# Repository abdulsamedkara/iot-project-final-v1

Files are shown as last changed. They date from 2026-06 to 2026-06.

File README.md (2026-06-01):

<div align="center">
  <h1>🧠 ESP32 SmartLab Asistanı (SmartLab Assistant)</h1>
  <p><strong>Yapay Zeka Destekli, Uçtan Uca Şifreli, Çoklu Sensörlü Akıllı Laboratuvar Sistemi</strong></p>
  <p>
    <a href="#english">🇬🇧 English</a> | <a href="#turkce">🇹🇷 Türkçe</a>
  </p>
</div>

---

## 🇬🇧 English

### 📖 About The Project

This project is an advanced **SmartLab Assistant** running on the **ESP32** microcontroller. It serves as a secure, voice-controlled IoT hub that monitors laboratory environments and interacts with users via **Local Large Language Models (LLM)** and **RAG (Retrieval-Augmented Generation)**. It features real-time sensor data streaming, AES-256 encrypted WebSocket communication, and a comprehensive Web UI for remote monitoring and control.

### ✨ Key Features

- **🗣️ Voice Interaction (STT & TTS):** Captures audio via I2S microphone (INMP441), streams it securely, and plays back LLM responses via I2S amplifier (MAX98357A).
- **🧠 AI & RAG Integration:** Processes voice commands using a local LLM (Ollama) and answers questions based on local PDF documents using RAG (Langchain).
- **🛡️ Secure Access & Encryption:** Uses MFRC522 RFID for user authentication. All audio data over WebSockets is encrypted using AES-256-CBC.
- **🌡️ Multi-Sensor Environment Monitoring:** Tracks Temperature & Humidity (DHT11), Air Quality/Smoke (MQ135), Light (LDR), Motion (PIR), Flame, and Vibration (SW-420).
- **⚙️ Automated Actuators:** Controls an exhaust Fan (PWM) and LED Strips automatically based on environmental thresholds or manual Web UI overrides.
- **🌐 Real-Time Web Dashboard:** A sleek Web UI to monitor live sensor telemetry, control actuators, and view chat history.

### 🛠️ Architecture & Technologies

- **Hardware:** ESP32, INMP441, MAX98357A, ILI9341 LCD, MFRC522 RFID, MQ135, DHT11, LDR, PIR, Flame, SW-420, L298N Motor Driver.
- **Embedded:** C, ESP-IDF (v5.x), FreeRTOS.
- **Server & Backend:** Python 3.10+, FastAPI, WebSockets, Piper TTS, Ollama (Local LLM), Langchain (RAG), ChromaDB.
- **Frontend:** HTML, CSS, JavaScript (Vanilla).

### 🖼️ Circuit Diagram

Below is the circuit diagram showing the hardware components and connections of the project. This diagram was prepared using **Fritzing**.

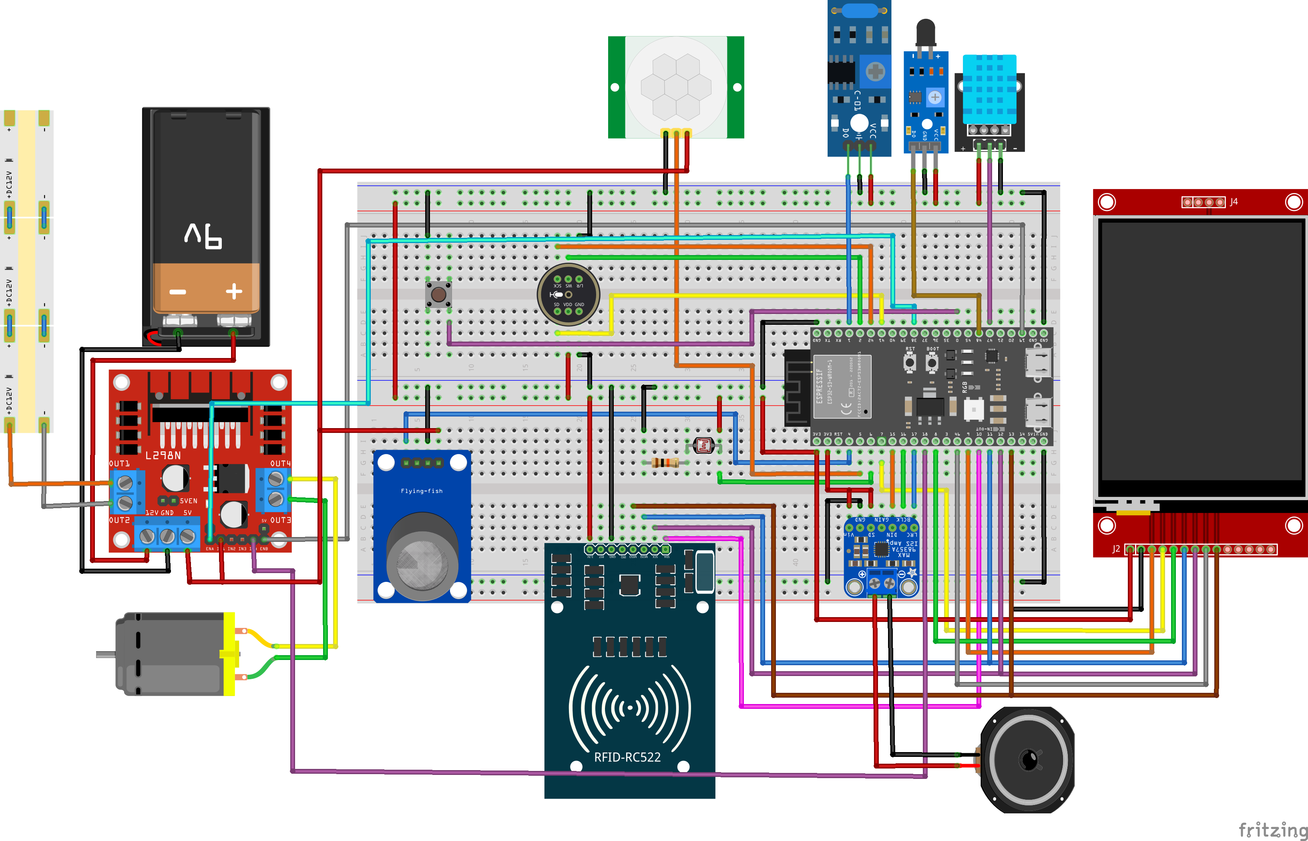
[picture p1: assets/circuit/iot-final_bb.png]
Circuit Diagram


### 🖥️ Web Dashboard Screenshots

Below are the screenshots of the Web UI used for live telemetry and environment control.

<p align="center">
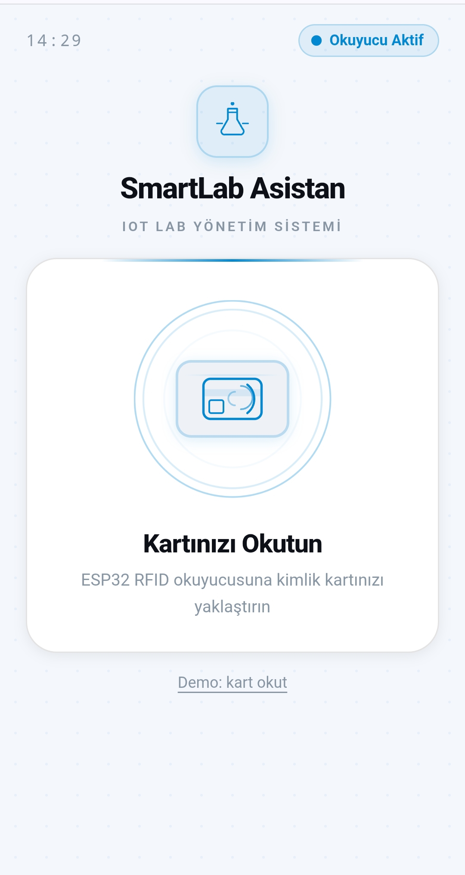
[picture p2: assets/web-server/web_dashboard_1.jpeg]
  
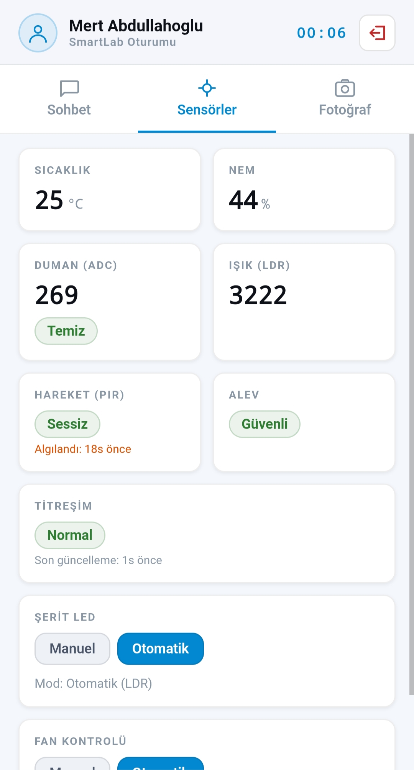
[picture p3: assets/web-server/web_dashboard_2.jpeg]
  
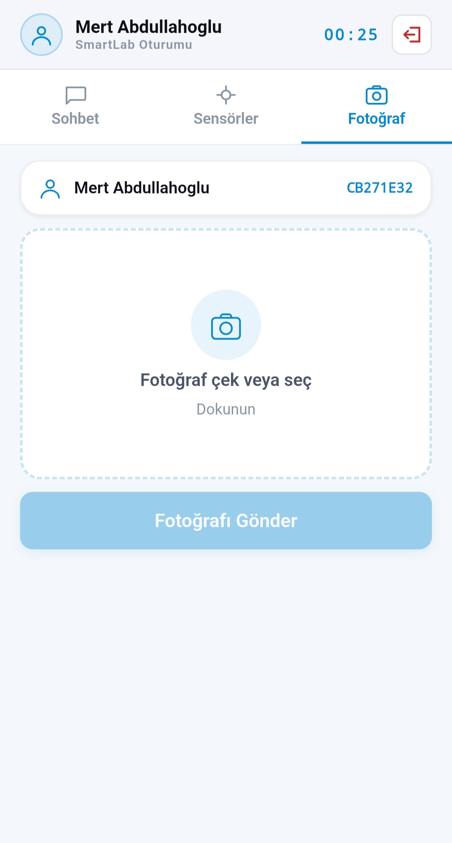
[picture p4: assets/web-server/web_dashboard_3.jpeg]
  
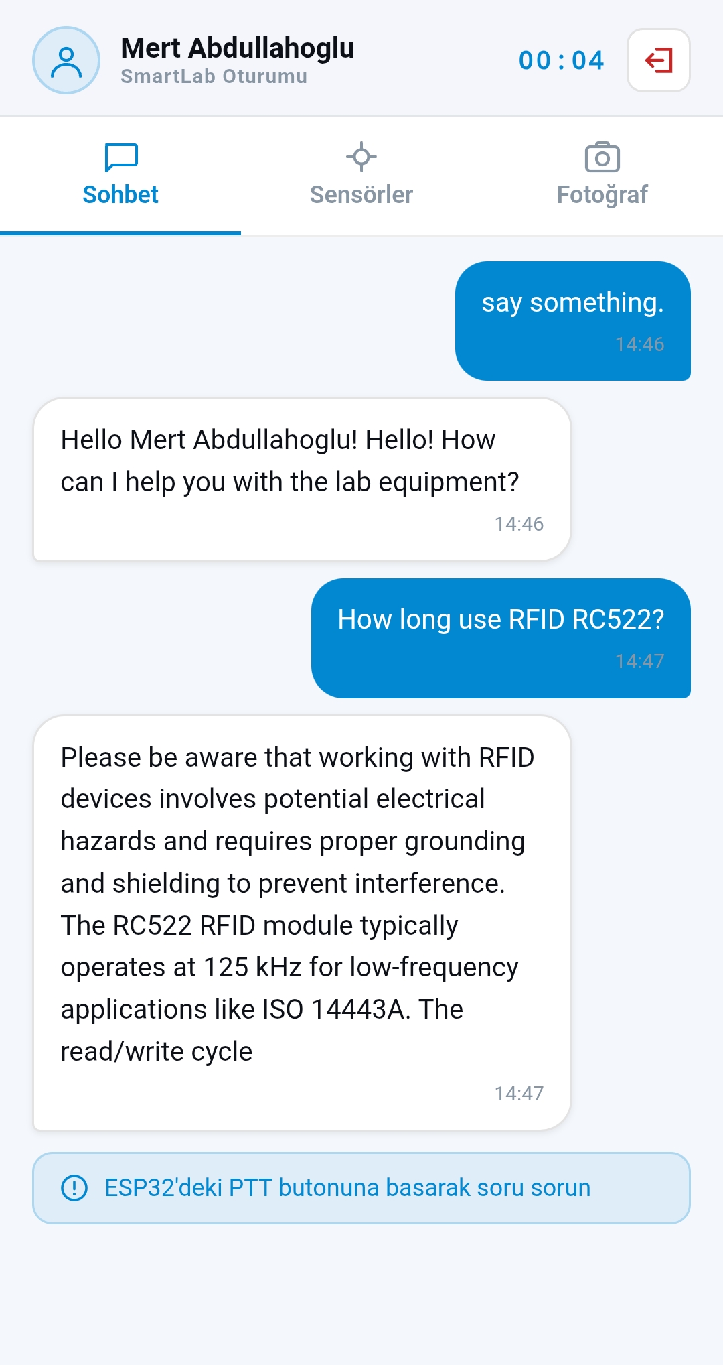
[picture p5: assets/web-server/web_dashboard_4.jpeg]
  
</p>

---

### 🚀 Getting Started

**Important Note:** Before building the project, update `main/config.h` with your Wi-Fi credentials (`WIFI_SSID`, `WIFI_PASSWORD`) and the local IP address of your server (`SERVER_HOST`).

#### 1. Ollama & Backend Setup

1. Download and install Ollama from [Ollama.com](https://ollama.com).
2. Pull the required models:
   
   ```bash
   ollama run gemma3:4b
   ollama pull nomic-embed-text
   ```
   
   *Note: If your Python server and Ollama are on different machines, or if you face connection issues, you must set `OLLAMA_HOST="0.0.0.0"` in your system environment variables before starting Ollama to allow external connections.*

#### 2. Python Server Setup

The backend handles LLM interaction, RAG, TTS, and Web UI hosting.

```bash
cd server
pip install -r requirements.txt
```

#### 3. Models & Dependencies (Manual Downloads)

For the TTS feature to work on Windows, the Piper binaries and voice models must be manually downloaded and placed in the `server` directory:

- **Piper TTS (Windows):** Download `piper.exe` and necessary DLLs from [Piper GitHub Releases](https://github.com/rhasspy/piper/releases) and extract them into the `server` folder.
- **Models (ONNX):** Download `tr_TR-dfki-medium` (for Turkish) or `en_GB-alba-medium` (for English) `.onnx` and `.onnx.json` files from [Piper Voices](https://huggingface.co/rhasspy/piper-voices/tree/main) and place them inside `server/tts_models/`.

#### 4. Running the Server

Once all dependencies and models are in place, you can start the backend server.

```bash
# Start the FastAPI server (Host Web UI and WebSocket)
uvicorn main:app --host 0.0.0.0 --port 8080
```

*Note: Place your PDF files in the `rag_pdf` folder for the RAG system to index them on startup.*  
*Access the Web UI by opening your browser and navigating to: **`http://localhost:8080`** (or the server's IP address).*

#### 5. ESP32 Setup (Firmware Build & Flash)

```bash
# Activate ESP-IDF environment
get_idf

# Build the project
idf.py build

# Flash code to ESP32 and open serial monitor
idf.py -p COMX flash monitor
```

### 🎮 How to Use

1. **Voice Assistant:** Press and hold the **PTT (Push-To-Talk)** button on the device to speak. Release the button to send your audio to the server. The AI will generate a response, and the ESP32 will play it back loudly.
2. **Web Dashboard:** Use the Web UI to monitor live sensor telemetry, view the conversation history, or manually control the LED and Fan.
3. **RFID Authentication:** Present your authorized RFID card to unlock and access the system.

### 👥 Developers

This project was developed within the scope of the **Internet of Things** course at the **Computer Engineering Department of Recep Tayyip Erdogan University**, under the supervision of **Assoc. Prof. Yıldıran Yılmaz**.

- **Mert Abdullahoğlu**
- **Abdül Samed Kara**

---

<br><hr><br>

## 🇹🇷 Türkçe

### 📖 Proje Hakkında

Bu proje, **ESP32** mikrodenetleyicisi üzerinde koşan gelişmiş bir **Akıllı Laboratuvar (SmartLab) Asistanı**'dır. Laboratuvar ortamını sürekli izleyen, kullanıcılarla sesli etkileşime giren, **Yerel Büyük Dil Modelleri (LLM)** ve **RAG (Geri Getirmeyle Güçlendirilmiş Üretim)** teknolojilerini kullanan uçtan uca şifreli bir IoT merkezidir. Gerçek zamanlı sensör telemetrisi ve web tabanlı bir kontrol paneli sunar.

### ✨ Temel Özellikler

- **🗣️ Sesli Etkileşim (STT & TTS):** I2S mikrofon ile sesi yakalar, şifreli yollar ve dönen metinsel LLM yanıtlarını I2S hoparlör üzerinden yüksek kalitede seslendirir.
- **🧠 Yapay Zeka & RAG:** Sesli komutlar yerel LLM (Ollama) ile işlenir. Yüklenen PDF dokümanları içerisinden RAG (Langchain) mantığıyla bağlamsal cevaplar üretilir.
- **🛡️ Güvenli Erişim ve Şifreleme:** Sisteme giriş MFRC522 RFID kart okuyucu ile yapılır. Ağ üzerinden geçen tüm ses verileri **AES-256-CBC** ile şifrelenir.
- **🌡️ Çoklu Sensör Takibi:** Sıcaklık ve Nem (DHT11), Hava Kalitesi/Duman (MQ135), Işık (LDR), Hareket (PIR), Alev ve Titreşim (SW-420) anlık takip edilir.
- **⚙️ Otomatik Aktüatörler:** Ortam koşullarına göre (sıcaklık, duman, ışık) Fan ve Şerit LED sistemleri otomatik çalışır veya Web UI üzerinden manuel yönetilebilir.
- **🌐 Gerçek Zamanlı Web Paneli:** Canlı sensör verilerini, sistem durumunu ve sohbet geçmişini izlemek için şık bir arayüz.

### 🛠️ Mimari ve Teknolojiler

- **Donanım:** ESP32, INMP441, MAX98357A, ILI9341 LCD, MFRC522 RFID, MQ135, DHT11, LDR, PIR, Alev Sensörü, SW-420 Titreşim Sensörü, L298N.
- **Gömülü Yazılım:** C, ESP-IDF (v5.x), FreeRTOS.
- **Sunucu ve Backend:** Python 3.10+, FastAPI, WebSockets, Piper TTS, Ollama (Local LLM), Langchain (RAG), ChromaDB.
- **Frontend:** HTML, CSS, JavaScript (Vanilla).

### 🖼️ Devre Şeması

Aşağıda projenin donanım bileşenlerini ve bağlantılarını gösteren devre şeması yer almaktadır. Bu şema **Fritzing** kullanılarak hazırlanmıştır.

Circuit Diagram

### 🖥️ Web Paneli Ekran Görüntüleri

Sistemi uzaktan izlemek, sensör verilerini anlık takip etmek ve cihazları kontrol etmek için kullanılan Web Arayüzüne ait ekran görüntüleri:

<p align="center">
  
  
  
  
</p>

---

### 🚀 Kurulum ve Çalıştırma

**Önemli Not:** Projeyi derlemeden önce `main/config.h` dosyasını açarak yerleşik olan değerlerin (`WIFI_SSID`, `WIFI_PASSWORD`, `SERVER_HOST`) yerine kendi Wi-Fi bilgilerinizi ve sunucu bilgisayarınızın yerel IP adresini girdiğinizden emin olun.

#### 1. Ollama ve Yapay Zeka Kurulumu

1. [Ollama.com](https://ollama.com) adresinden Ollama'yı kurun.
2. Gerekli modelleri terminalden çekin:
   
   ```bash
   ollama run gemma3:4b
   ollama pull nomic-embed-text
   ```
   
   *Not: Eğer Python sunucunuz ile Ollama farklı bilgisayarlarda çalışacaksa veya bağlantı reddedildi hatası alırsanız, Ollama'yı başlatmadan önce sistem ortam değişkenlerine `OLLAMA_HOST="0.0.0.0"` ekleyerek dış bağlantılara izin vermeniz gerekir.*

#### 2. Python Sunucusu Kurulumu

Backend sistemi LLM, RAG, TTS işlemlerini ve Web Arayüzünü sunar.

```bash
cd server
pip install -r requirements.txt
```

#### 3. Gerekli Model ve Bağımlılık Dosyaları (Manuel Kurulum)

Projenin TTS (Seslendirme) özelliğinin Windows üzerinde sorunsuz çalışabilmesi için şu dosyaların manuel olarak indirilip `server` klasörüne yerleştirilmesi gerekir:

- **Piper TTS (Windows):** [Piper GitHub Releases](https://github.com/rhasspy/piper/releases) üzerinden Windows sürümünü indirin; içindeki `piper.exe` ve tüm `.dll` dosyalarını `server` klasörünün ana dizinine kopyalayın.
- **Modeller (ONNX):** [Piper Voices](https://huggingface.co/rhasspy/piper-voices/tree/main) üzerinden Türkçe için `tr_TR-dfki-medium` (veya İngilizce için `en_GB-alba-medium`) `.onnx` ve `.onnx.json` dosyalarını indirip `server/tts_models/` klasörüne yerleştirin.

#### 4. Sunucuyu Başlatma

Tüm bağımlılıklar ve model dosyaları yerleştirildikten sonra sunucuyu çalıştırabilirsiniz.

```bash
# FastAPI Sunucusunu Başlatın
uvicorn main:app --host 0.0.0.0 --port 8080
```

*Not: RAG sisteminin referans alacağı PDF dokümanlarınızı `rag_pdf` klasörüne eklemeyi unutmayın.*  
*Web paneline erişmek için tarayıcınızdan şu adrese gidin: **`http://localhost:8080`** (veya sunucunun IP adresi).*

#### 5. ESP32 Kurulumu (Firmware Build & Flash)

```bash
# ESP-IDF ortamını aktif edin (Örn: get_idf)
get_idf

# Projeyi derleyin
idf.py build

# ESP32'ye kodu yükleyin ve seri monitörü başlatın 
idf.py -p COMX flash monitor
```

### 🎮 Nasıl Kullanılır?

1. **Sesli Asistan:** Cihaz üzerindeki **PTT (Bas-Konuş)** butonuna basılı tutarak konuşun. Butonu bıraktığınızda sesiniz sunucuya iletilecek, yapay zeka cevap üretecek ve cihaz size sesli olarak yanıt verecektir.
2. **Web Paneli:** Canlı sensör verilerini izlemek, sohbet geçmişini okumak veya Fan/LED gibi cihazları manuel kontrol etmek için tarayıcınızdan Web arayüzüne girin.
3. **RFID Girişi:** Sistemin kilidini açmak ve etkileşime girmek için yetkili RFID kartınızı okutun.

### 👥 Geliştiriciler

Bu proje, **Recep Tayyip Erdoğan Üniversitesi Bilgisayar Mühendisliği** bölümünde **Nesnelerin İnterneti (Internet of Things)** dersi kapsamında, **Doç. Dr. Yıldıran Yılmaz** danışmanlığında hazırlanmıştır.

- **Mert Abdullahoğlu**
- **Abdül Samed Kara**

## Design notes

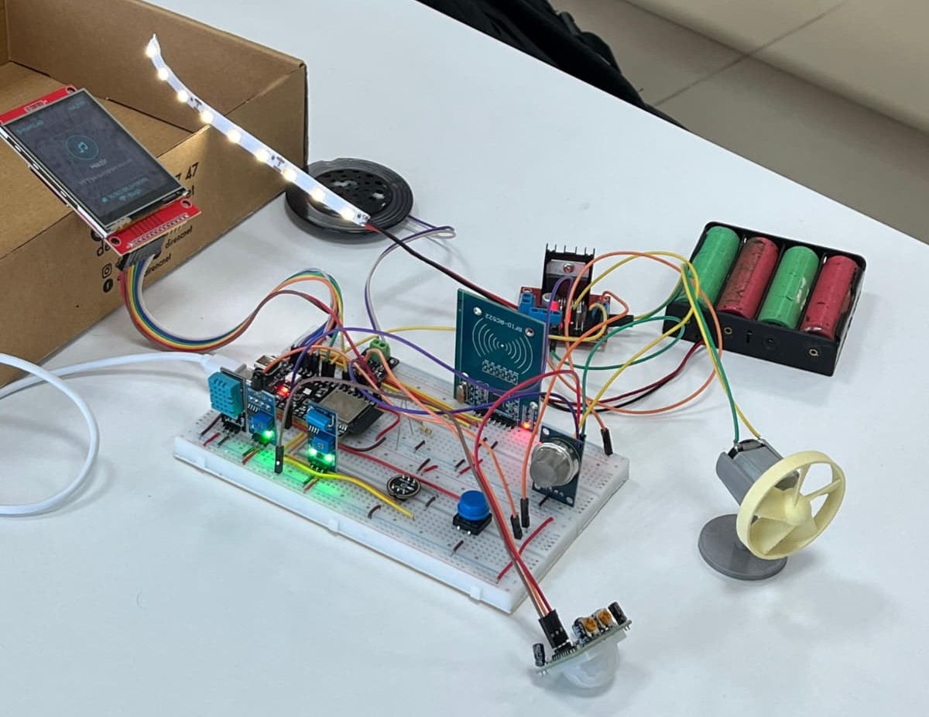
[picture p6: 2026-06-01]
assets/circuit/circuit-real.jpeg

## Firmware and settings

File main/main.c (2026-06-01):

// SmartLab Assistant Main Application (Phase 1)
// Handles WiFi connection, WebSocket communication, AES-256 encrypted sessions,
// RFID reading, PTT audio recording, AI response processing, and audio playback.
//
// Configuration parameters such as WIFI_SSID and SERVER_HOST should be edited in config.h

#include "freertos/FreeRTOS.h"
#include "freertos/task.h"
#include "freertos/event_groups.h"

#include "esp_log.h"
#include "esp_wifi.h"
#include "esp_event.h"
#include "nvs_flash.h"
#include "driver/gpio.h"
#include "driver/spi_master.h"
#include "esp_heap_caps.h"

#include "config.h"
#include "i2s_mic.h"
#include "i2s_player.h"
#include "crypto.h"
#include "ws_client.h"
#include "rfid.h"
#include "smoke_sensor.h"
#include "fan_control.h"
#include "led_strip_ctrl.h"
#include "dht11.h"
#include "ui/display.h"

static const char *TAG = "main";

// Event group bits for WiFi connection status
#define WIFI_CONNECTED_BIT  BIT0
#define WIFI_FAIL_BIT       BIT1

// Event group handle used to track WiFi events
static EventGroupHandle_t s_wifi_eg;
// Retry counter for WiFi connection attempts
static int s_retry = 0;

// Callback function to handle WiFi and IP events
static void wifi_event_handler(void *arg, esp_event_base_t base,
                                int32_t id, void *data)
{
    if (base == WIFI_EVENT && id == WIFI_EVENT_STA_START) {
        // Start connection when WiFi station is initialized
        esp_wifi_connect();
    } else if (base == WIFI_EVENT && id == WIFI_EVENT_STA_DISCONNECTED) {
        // Attempt to reconnect if disconnected, up to WIFI_MAX_RETRY times
        if (s_retry < WIFI_MAX_RETRY) {
            esp_wifi_connect();
            s_retry++;
            ESP_LOGW(TAG, "Reconnecting to WiFi (%d/%d)...", s_retry, WIFI_MAX_RETRY);
        } else {
            // Signal failure if maximum retries reached
            xEventGroupSetBits(s_wifi_eg, WIFI_FAIL_BIT);
        }
    } else if (base == IP_EVENT && id == IP_EVENT_STA_GOT_IP) {
        // Connection successful, IP obtained
        ip_event_got_ip_t *ev = (ip_event_got_ip_t *)data;
        ESP_LOGI(TAG, "IP: " IPSTR, IP2STR(&ev->ip_info.ip));
        s_retry = 0;
        xEventGroupSetBits(s_wifi_eg, WIFI_CONNECTED_BIT);
    }
}

// Initializes the WiFi in station mode and connects to the configured AP
static esp_err_t wifi_init(void)
{
    s_wifi_eg = xEventGroupCreate();
    esp_netif_create_default_wifi_sta();

    wifi_init_config_t cfg = WIFI_INIT_CONFIG_DEFAULT();
    ESP_ERROR_CHECK(esp_wifi_init(&cfg));

    esp_event_handler_instance_t eh_wifi, eh_ip;
    ESP_ERROR_CHECK(esp_event_handler_instance_register(
        WIFI_EVENT, ESP_EVENT_ANY_ID, &wifi_event_handler, NULL, &eh_wifi));
    ESP_ERROR_CHECK(esp_event_handler_instance_register(
        IP_EVENT, IP_EVENT_STA_GOT_IP, &wifi_event_handler, NULL, &eh_ip));

    wifi_config_t wc = {
        .sta = {
            .ssid     = WIFI_SSID,
            .password = WIFI_PASSWORD,
            .threshold.authmode = WIFI_AUTH_WPA2_PSK,
        },
    };
    ESP_ERROR_CHECK(esp_wifi_set_mode(WIFI_MODE_STA));
    ESP_ERROR_CHECK(esp_wifi_set_config(WIFI_IF_STA, &wc));
    ESP_ERROR_CHECK(esp_wifi_start());
    // Disable power save mode to prevent disconnections during WebSocket and audio streaming tasks
    ESP_ERROR_CHECK(esp_wifi_set_ps(WIFI_PS_NONE));

    // Block until connection is established or maximum retries are reached
    EventBits_t bits = xEventGroupWaitBits(s_wifi_eg,
        WIFI_CONNECTED_BIT | WIFI_FAIL_BIT,
        pdFALSE, pdFALSE, portMAX_DELAY);

    return (bits & WIFI_CONNECTED_BIT) ? ESP_OK : ESP_FAIL;
}

// Initializes the SPI bus which is shared between the MFRC522 RFID reader and ILI9341 display
static void spi_bus_init(void)
{
    spi_bus_config_t bus = {
        .mosi_io_num     = SPI_MOSI_GPIO,
        .miso_io_num     = SPI_MISO_GPIO,
        .sclk_io_num     = SPI_SCK_GPIO,
        .quadwp_io_num   = -1,
        .quadhd_io_num   = -1,
        // The maximum transfer size allows for LVGL buffer updates
        .max_transfer_sz = TFT_WIDTH * LVGL_BUF_LINES * 2 + 8,
    };
    ESP_ERROR_CHECK(spi_bus_initialize(SPI_HOST, &bus, SPI_DMA_CH_AUTO));
    ESP_LOGI(TAG, "SPI bus ready: MOSI=%d MISO=%d SCK=%d",
             SPI_MOSI_GPIO, SPI_MISO_GPIO, SPI_SCK_GPIO);
}

// Configures the Push-To-Talk (PTT) button GPIO pin
static void ptt_init(void)
{
    gpio_config_t gc = {
        .pin_bit_mask = 1ULL << PTT_GPIO,
        .mode         = GPIO_MODE_INPUT,
        .pull_up_en   = GPIO_PULLUP_ENABLE,
        .intr_type    = GPIO_INTR_DISABLE,
    };
    gpio_config(&gc);
}

// Checks if the PTT button is currently pressed (active low)
static inline bool ptt_pressed(void) { return gpio_get_level(PTT_GPIO) == 0; }

// Independent FreeRTOS task running on Core 0 to monitor the smoke sensor
// Checks the sensor every 500 ms and triggers an alarm if thresholds are exceeded
static void smoke_task(void *arg)
{
    static const char *TAG2 = "smoke_task";

    // Wait for the analog sensor to warm up and stabilize
    ESP_LOGI(TAG2, "Waiting for sensor warmup (%d ms)...", SMOKE_WARMUP_MS);
    while (!smoke_sensor_warmup_done()) {
        vTaskDelay(pdMS_TO_TICKS(1000));
    }
    ESP_LOGI(TAG2, "Warmup complete. Starting measurement.");

    int  alert_count = 0;
    bool in_alert    = false;

    while (1) {
        int adc = smoke_sensor_read_avg();

        if (adc < 0) {
            vTaskDelay(pdMS_TO_TICKS(500));
            continue;
        }

        ESP_LOGI(TAG2, "ADC=%d", adc);

        // Control fan speed based on smoke concentration
        // Overrides temperature-based fan control when smoke is detected
        if (adc >= SMOKE_ADC_FULL) {
            fan_full();
        } else if (adc >= SMOKE_ADC_HALF) {
            fan_half();
        } else if (adc >= SMOKE_ADC_CLEAR) {
            fan_half();
        }
        // If adc < SMOKE_ADC_CLEAR, leave fan control to the sensor_broadcast_task

        // Debounce logic for the alarm: requires 3 consecutive high readings to trigger
        if (adc >= SMOKE_ADC_HALF) {
            if (++alert_count >= 3 && !in_alert) {
                in_alert = true;
                ESP_LOGW(TAG2, "SMOKE ALARM! ADC=%d", adc);
                char msg[32];
                snprintf(msg, sizeof(msg), "ADC: %d", adc);
                display_switch(SCREEN_SMOKE_ALERT, msg);
            }
        } else {
            if (alert_count > 0) alert_count--;
            // Clear the alarm if smoke levels drop below the clear threshold
            if (in_alert && adc < SMOKE_ADC_CLEAR) {
                in_alert = false;
                ESP_LOGI(TAG2, "Smoke decreased. ADC=%d", adc);
                display_switch(SCREEN_READY, NULL);
            }
        }

        vTaskDelay(pdMS_TO_TICKS(500));
    }
}

// Shared variables for DHT11 sensor data
// Written by dht11_task and read by sensor_broadcast_task
static volatile int s_dht_temp = 0;
static volatile int s_dht_hum  = 0;

// Task to read temperature and humidity from the DHT11 sensor periodically
static void dht11_task(void *arg)
{
    static const char *TAG3 = "dht11_task";
    dht11_reading_t dht_data;

    ESP_LOGI(TAG3, "Starting DHT11 reading...");

    while (1) {
        esp_err_t res = dht11_read(DHT11_GPIO, &dht_data);
        if (res == ESP_OK) {
            s_dht_temp = dht_data.temperature;
            s_dht_hum  = dht_data.humidity;
            ESP_LOGI(TAG3, "Temperature: %dC, Humidity: %%%d", dht_data.temperature, dht_data.humidity);
        } else {
            ESP_LOGW(TAG3, "DHT11 read failed (error: %d)", res);
        }
        vTaskDelay(pdMS_TO_TICKS(DHT11_UPDATE_MS));
    }
}

// LED operation mode flag: 0 indicates manual mode via web UI, 1 indicates automatic mode via LDR
static volatile int s_led_auto = 1;

// Task to read the Light Dependent Resistor (LDR) analog value and control the LED strip brightness
static void ldr_task(void *arg)
{
    static const char *TAG_LDR = "ldr_task";
    
    ESP_LOGI(TAG_LDR, "Starting LDR reading (Analog GPIO %d)...", LDR_AOUT_GPIO);

    while (1) {
        int ldr_adc = ldr_sensor_read_avg();
        if (ldr_adc >= 0) {
            ESP_LOGI(TAG_LDR, "LDR ADC = %d", ldr_adc);
            // Adjust LED brightness automatically if auto mode is enabled
            if (s_led_auto) {
                if (ldr_adc <= LDR_LED_DARK_ADC) {
                    // Maximum brightness in dark conditions
                    led_strip_set_brightness(255);
                } else if (ldr_adc >= LDR_LED_BRIGHT_ADC) {
                    // Turn off LED in bright conditions
                    led_strip_off();
                } else {
                    // Linearly interpolate brightness for intermediate light levels
                    // LDR_LED_DARK_ADC maps to full brightness (255)
                    // LDR_LED_BRIGHT_ADC maps to off (0)
                    int range = LDR_LED_BRIGHT_ADC - LDR_LED_DARK_ADC;
                    int adc_diff = ldr_adc - LDR_LED_DARK_ADC;
                    uint8_t brightness = (uint8_t)(255 - (adc_diff * 255 / range));
                    led_strip_set_brightness(brightness);
                }
            }
        } else {
            ESP_LOGW(TAG_LDR, "LDR read error!");
        }
        vTaskDelay(pdMS_TO_TICKS(1000));
    }
}

// Task to monitor the PIR (Passive Infrared) motion sensor
static void pir_task(void *arg)
{
    static const char *TAG_PIR = "pir_task";
    
    // Configure the PIR sensor data pin as input
    gpio_config_t io_conf = {
        .pin_bit_mask = (1ULL << PIR_GPIO),
        .mode = GPIO_MODE_INPUT,
        // Most PIR modules (e.g., HC-SR501) have their own pull-down resistor
        .pull_up_en = GPIO_PULLUP_DISABLE,
        .pull_down_en = GPIO_PULLDOWN_DISABLE,
        .intr_type = GPIO_INTR_DISABLE
    };
    gpio_config(&io_conf);

    int last_state = -1;
    ESP_LOGI(TAG_PIR, "Listening to PIR motion sensor (GPIO %d)...", PIR_GPIO);

    while (1) {
        int current_state = gpio_get_level(PIR_GPIO);
        
        // Log state changes when motion starts or stops
        if (current_state != last_state) {
            if (current_state == 1) {
                ESP_LOGI(TAG_PIR, "ALARM: Motion detected!");
            } else {
                ESP_LOGI(TAG_PIR, "Motion ended, environment is calm.");
            }
            last_state = current_state;
        }
        
        // Check the sensor state every 500 ms
        vTaskDelay(pdMS_TO_TICKS(500));
    }
}

// Task to monitor the flame sensor for fire detection
static void flame_task(void *arg)
{
    static const char *TAG_FLAME = "flame_task";
    
    gpio_config_t io_conf = {
        .pin_bit_mask = (1ULL << FLAME_GPIO),
        .mode = GPIO_MODE_INPUT,
        // Enable pull-up to keep the sensor DO (Digital Out) signal stable
        .pull_up_en = GPIO_PULLUP_ENABLE,
        .pull_down_en = GPIO_PULLDOWN_DISABLE,
        .intr_type = GPIO_INTR_DISABLE
    };
    gpio_config(&io_conf);

    int last_state = -1;
    ESP_LOGI(TAG_FLAME, "Listening to flame sensor (GPIO %d)...", FLAME_GPIO);

    while (1) {
        int current_state = gpio_get_level(FLAME_GPIO);
        
        if (current_state != last_state) {
            // Most flame modules output 0 (LOW) when a flame is detected, and normally 1 (HIGH).
            if (current_state == 0) {
                ESP_LOGE(TAG_FLAME, "FIRE ALARM: Flame detected!");
            } else {
                ESP_LOGI(TAG_FLAME, "Flame ended, environment is safe.");
            }
            last_state = current_state;
        }
        
        // Check the sensor state every 500 ms
        vTaskDelay(pdMS_TO_TICKS(500));
    }
}

// Task to monitor the vibration sensor for physical shocks or movements
static void vib_task(void *arg)
{
    static const char *TAG_VIB = "vib_task";
    
    gpio_config_t io_conf = {
        .pin_bit_mask = (1ULL << VIB_GPIO),
        .mode = GPIO_MODE_INPUT,
        .pull_up_en = GPIO_PULLUP_DISABLE, 
        .pull_down_en = GPIO_PULLDOWN_DISABLE,
        .intr_type = GPIO_INTR_DISABLE
    };
    gpio_config(&io_conf);

    int last_state = -1;
    ESP_LOGI(TAG_VIB, "Listening to vibration sensor (GPIO %d)...", VIB_GPIO);

    while (1) {
        int current_state = gpio_get_level(VIB_GPIO);
        
        if (current_state != last_state) {
            // SW-420 rapidly switches between 1 and 0 when vibration is detected
            if (current_state == 1) {
                ESP_LOGE(TAG_VIB, "WARNING: Vibration / Shock detected!");
            }
            last_state = current_state;
        }
        
        // Read slightly faster at 100ms since vibration events are instantaneous
        vTaskDelay(pdMS_TO_TICKS(100));
    }
}

// Sensor Broadcast Task to send telemetry to the WebSocket server

// Fan mode: 0 for manual control via UI, 1 for automatic control based on temperature
static volatile int  s_fan_mode  = 1;   // Auto at startup
static volatile int  s_fan_speed = 0;   // Manual mode speed (0-100)
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
void app_main(void)
{
    // 1. Initialize NVS (Non-Volatile Storage)
    // Used by WiFi to store connection settings
    esp_err_t ret = nvs_flash_init();
    if (ret == ESP_ERR_NVS_NO_FREE_PAGES ||
        ret == ESP_ERR_NVS_NEW_VERSION_FOUND) {
        ESP_ERROR_CHECK(nvs_flash_erase());
        ret = nvs_flash_init();
    }
    ESP_ERROR_CHECK(ret);

    // Initialize TCP/IP stack and default event loop
    // Must be done before WiFi and LVGL initialization
    ESP_ERROR_CHECK(esp_netif_init());
    ESP_ERROR_CHECK(esp_event_loop_create_default());

    // 2. Initialize the shared SPI Bus for TFT and RFID modules
    spi_bus_init();

    // 3. Initialize Display and show startup message
    ESP_ERROR_CHECK(display_init());
    display_switch(SCREEN_IDLE, "Initializing...");

    // 4. Initialize WiFi and attempt to connect
    display_switch(SCREEN_IDLE, "Connecting to WiFi...");
    if (wifi_init() != ESP_OK) {
        display_switch(SCREEN_ERROR, "WiFi connection error!");
        ESP_LOGE(TAG, "Failed to start WiFi.");
        return;
    }

    // 5. Initialize I2S for microphone (input) and speaker (output)
    ESP_ERROR_CHECK(i2s_mic_init());
    ESP_ERROR_CHECK(i2s_player_init(SPK_SAMPLE_RATE, 16, 1));

    // 6. Initialize Push-To-Talk button
    ptt_init();

    // 7. Initialize MFRC522 RFID reader
    ESP_ERROR_CHECK(rfid_init());

    // Initialize environmental sensors, fan control, and LED strip
    ESP_ERROR_CHECK(smoke_sensor_init());
    ESP_ERROR_CHECK(ldr_sensor_init());
    ESP_ERROR_CHECK(fan_control_init());
    ESP_ERROR_CHECK(led_strip_init());

    // Start background tasks for each sensor
    xTaskCreatePinnedToCore(smoke_task, "smoke", 3072, NULL, 3, NULL, 0);
    xTaskCreatePinnedToCore(dht11_task, "dht11", 4096, NULL, 3, NULL, 0);
    xTaskCreatePinnedToCore(ldr_task, "ldr", 4096, NULL, 3, NULL, 0);
    xTaskCreatePinnedToCore(pir_task, "pir", 4096, NULL, 3, NULL, 0);
    xTaskCreatePinnedToCore(flame_task, "flame", 4096, NULL, 3, NULL, 0);
    xTaskCreatePinnedToCore(vib_task, "vib", 4096, NULL, 3, NULL, 0);

    // Start the broadcast task to periodically send sensor data to the web UI
    xTaskCreatePinnedToCore(sensor_broadcast_task, "sensor_bc", 4096, NULL, 2, NULL, 0);

    // 8. Initialize WebSocket client and acquire session key
    // Reconnection is handled automatically if the server is unreachable
    display_switch(SCREEN_IDLE, "Connecting to server...");
    ESP_ERROR_CHECK(ws_client_init(on_audio, on_text));

    while (ws_client_wait_session(15000) != ESP_OK) {
        display_switch(SCREEN_ERROR, "Server not found\nRetrying...");
        ESP_LOGW(TAG, "Failed to get session, retrying in 10s...");
        ws_client_deinit();
        vTaskDelay(pdMS_TO_TICKS(10000));
        display_switch(SCREEN_IDLE, "Connecting to server...");
        ESP_ERROR_CHECK(ws_client_init(on_audio, on_text));
    }

    // 9. Allocate PSRAM recording buffer for audio capture
    // Buffer size: 16kHz × 2 Bytes × 15 seconds = 480KB
    int16_t *rec_buf = heap_caps_malloc(RECORD_BUF_SIZE, MALLOC_CAP_SPIRAM);
    if (!rec_buf) {
        ESP_LOGE(TAG, "Failed to allocate PSRAM recording buffer!");
        return;
    }

    display_switch(SCREEN_IDLE, "Please swipe your RFID card");
    ESP_LOGI(TAG, "Ready - Waiting for RFID card...");

    // Application Main Loop: Handles RFID, Audio Recording, Encryption, and Playback
    rfid_card_t last_card  = {0};
    bool        session_ok = false;
    int         rfid_fail_count = 0;

    while (1) {

        // Check if a logout request was received from the server
        if (s_logout_req) {
            s_logout_req = false;
            session_ok   = false;
            memset(&last_card, 0, sizeof(last_card));
            s_username[0] = '\0';
            fan_off();
            display_switch(SCREEN_IDLE, "Please swipe your RFID card");
            ESP_LOGI(TAG, "Logout - Returned to RFID waiting screen");
        }

        // Wait for a valid RFID card scan before allowing PTT interaction
        if (!session_ok) {
            rfid_card_t card;
            if (rfid_poll(&card)) {
                rfid_fail_count = 0;
                // Process the card only if it's a new swipe
                if (!rfid_uid_equal(&card, &last_card)) {
                    last_card = card;
                    char uid[32];
                    rfid_uid_to_str(&card, uid, sizeof(uid));
                    ESP_LOGI(TAG, "Card: %s", uid);

                    // Send the scanned UID to the server for authentication
                    s_username[0] = '\0';
                    ws_client_send_rfid(uid);
                    vTaskDelay(pdMS_TO_TICKS(600));  // Wait for server to respond with user details

                    char msg[80];
                    snprintf(msg, sizeof(msg), "Welcome%s%s!",
                             strlen(s_username) ? ", " : "",
                             strlen(s_username) ? s_username : "");

                    display_switch(SCREEN_RFID_READ, msg);
                    vTaskDelay(pdMS_TO_TICKS(2000));

                    session_ok = true;
                    display_switch(SCREEN_READY, NULL);
                }
            } else {
                // Recover the MFRC522 module if reading fails 5 consecutive times
                if (++rfid_fail_count >= 5) {
                    rfid_fail_count = 0;
                    rfid_init();  // Soft reset and reopen the antenna
                    ESP_LOGW(TAG, "RFID recovery performed");
                }
            }
            vTaskDelay(pdMS_TO_TICKS(200));
            continue;
        }

        // Wait for the user to press the Push-To-Talk button
        if (!ptt_pressed()) {
            vTaskDelay(pdMS_TO_TICKS(20));
            continue;
        }
        vTaskDelay(pdMS_TO_TICKS(50));   // Debounce delay
        if (!ptt_pressed()) continue;

        // Record audio from the microphone while the PTT button is held
        display_switch(SCREEN_RECORDING, NULL);
        ESP_LOGI(TAG, "Recording started...");

        size_t total   = 0;
        const size_t CHUNK   = 512;
        const size_t MAX_SMP = RECORD_BUF_SIZE / sizeof(int16_t);

        while (ptt_pressed() && total + CHUNK <= MAX_SMP) {
            size_t got = 0;
            i2s_mic_read(rec_buf + total, CHUNK, &got, 200);
            total += got;
        }

        size_t pcm_bytes = total * sizeof(int16_t);
        ESP_LOGI(TAG, "Recording finished: %.2fs (%zu B)",
                 (float)total / MIC_SAMPLE_RATE, pcm_bytes);

        // Discard very short recordings (less than 0.5 seconds)
        if (pcm_bytes < MIC_SAMPLE_RATE / 2) {
            ESP_LOGW(TAG, "Too short, skipping.");
            display_switch(SCREEN_READY, NULL);
            continue;
        }

        // Encrypt the recorded audio using AES-256 before transmission
        display_switch(SCREEN_PROCESSING, "AI processing...");

        const uint8_t *key = ws_client_get_session_key();
        if (!key) {
            display_switch(SCREEN_ERROR, "Session error");
            session_ok = false;
            continue;
        }

        // Apply PKCS#7 padding to the audio buffer
        size_t padded = crypto_pad_pcm((uint8_t *)rec_buf, pcm_bytes,
                                        RECORD_BUF_SIZE);
        if (!padded) { display_switch(SCREEN_ERROR, "Padding error"); continue; }

        uint8_t *cipher = heap_caps_malloc(padded, MALLOC_CAP_SPIRAM);
        uint8_t  iv[CRYPTO_IV_LEN];
        if (!cipher) { display_switch(SCREEN_ERROR, "Memory error"); continue; }

        if (crypto_encrypt(key, (uint8_t *)rec_buf, padded, iv, cipher) != ESP_OK) {
            free(cipher);
            display_switch(SCREEN_ERROR, "Encryption error");
            continue;
        }

        // Transmit the encrypted audio frame over WebSocket
        s_rsp_ready = false;
        esp_err_t err = ws_client_send_audio(iv, cipher, padded);
        free(cipher);

        if (err != ESP_OK) {
            display_switch(SCREEN_ERROR, "Transmission error");
            continue;
        }

        // Wait for the AI's audio response (up to 60 seconds timeout)
        uint32_t wait = 60000 / 50;
        while (!s_rsp_ready && wait-- > 0) vTaskDelay(pdMS_TO_TICKS(50));

        if (!s_rsp_ready) {
            display_switch(SCREEN_ERROR, "Response timeout");
            continue;
        }

        // Play the received PCM audio response through the speaker
        display_switch(SCREEN_SPEAKING, NULL);
        ESP_LOGI(TAG, "Playing: %zu bytes", s_rsp_len);
        i2s_player_play(s_rsp_pcm, s_rsp_len);

        display_switch(SCREEN_READY, NULL);
        ESP_LOGI(TAG, "Completed.\n");
    }
}

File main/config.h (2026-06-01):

#pragma once

// WiFi Configuration
// These are the credentials used by the ESP32 to connect to the local network.
#define WIFI_SSID           "Raspi"
#define WIFI_PASSWORD       "00000000"
#define WIFI_MAX_RETRY      10

// AI Server Configuration
// Defines the endpoint where the AI backend is running.
#define SERVER_HOST         "10.162.138.241"   // The local IP address of the PC running the server
#define SERVER_PORT         8080
#define SERVER_WS_URI       "ws://" SERVER_HOST ":8080/ws"

// SPI Bus Configuration
// This SPI bus is shared between the MFRC522 RFID reader and the ILI9341 TFT display.
#define SPI_MOSI_GPIO       11
#define SPI_MISO_GPIO       13
#define SPI_SCK_GPIO        12
#define SPI_HOST            SPI2_HOST

// MFRC522 RFID Configuration
// Pinout and speed settings for the RFID module.
#define RFID_CS_GPIO        10
#define RFID_RST_GPIO       (-1)               // Hardware reset pin is not used; we rely on software reset instead
#define RFID_SPI_FREQ_HZ    (2 * 1000 * 1000)  // Running at 2 MHz provides much better stability on a breadboard setup

// ILI9341 TFT Display Configuration
// Pinout and screen dimensions for the display module.
#define TFT_CS_GPIO         9
#define TFT_DC_GPIO         8
#define TFT_RST_GPIO        7
#define TFT_BL_GPIO         46
#define TFT_SPI_FREQ_HZ     (40 * 1000 * 1000) // The display handles 40 MHz SPI speed smoothly
#define TFT_WIDTH           240
#define TFT_HEIGHT          320

// INMP441 I2S Microphone Configuration
// Pinout and sampling settings for audio input.
#define MIC_I2S_PORT        I2S_NUM_0
#define MIC_SCK_GPIO        42
#define MIC_WS_GPIO         2
#define MIC_SD_GPIO         41
#define MIC_SAMPLE_RATE     16000   // 16 kHz is the ideal sampling rate for Whisper AI models

// MAX98357A I2S Amplifier/Speaker Configuration
// Pinout and sampling settings for audio output.
#define SPK_I2S_PORT        I2S_NUM_1
#define SPK_BCK_GPIO        16
#define SPK_WS_GPIO         17
#define SPK_DIN_GPIO        15
#define SPK_SAMPLE_RATE     22050   // 22.05 kHz matches the default output rate of Piper TTS

// Push-to-Talk Button Configuration
#define PTT_GPIO            0       // Uses INPUT_PULLUP, so a LOW state means the button is pressed

// MQ135 Gas and Smoke Sensor Configuration
// Defines pins and thresholds for air quality monitoring.
#define SMOKE_AOUT_GPIO     4               // Analog pin for density reading (ADC1_CH3)
#define SMOKE_DOUT_GPIO     14              // Optional digital threshold output pin
#define SMOKE_ADC_CHANNEL   ADC_CHANNEL_3   // GPIO4 corresponds to ADC1_CH3
#define SMOKE_ADC_CLEAR     800             // ADC values below this indicate clean air
#define SMOKE_ADC_HALF      1500            // Triggers the fan to run at 50% speed
#define SMOKE_ADC_FULL      2000            // Triggers the fan to run at 100% speed and issues a warning
#define SMOKE_WARMUP_MS     30000           // The MQ135 sensor requires 30 seconds to heat up and stabilize
#define SMOKE_SAMPLE_COUNT  32              // We average 32 samples to filter out electrical noise

// L298N Fan Motor Driver Configuration
// PWM settings for controlling the cooling fan speed.
#define FAN_IN4_GPIO        18              // Direction control pin (HIGH = forward)
#define FAN_ENA_GPIO        21              // PWM speed control pin
#define FAN_LEDC_TIMER      LEDC_TIMER_1
#define FAN_LEDC_CHANNEL    LEDC_CHANNEL_1
#define FAN_PWM_FREQ_HZ     25000           // 25 kHz prevents audible coil whine from the motor
#define FAN_DUTY_RES        LEDC_TIMER_8_BIT // 8-bit resolution means duty cycle goes from 0 to 255

// Buffer Sizes (PSRAM)
// Memory allocations for holding audio data during recording and playback.
#define MAX_RECORD_SECONDS  15
// Calculation: 16000 samples/s * 2 bytes/sample * 15 seconds = 480,000 bytes
#define RECORD_BUF_SIZE     (MIC_SAMPLE_RATE * 2 * MAX_RECORD_SECONDS)

// Calculation: 22050 samples/s * 2 bytes/sample * 30 seconds + WAV header = ~1.3 MB
#define RESP_BUF_SIZE       (SPK_SAMPLE_RATE * 2 * 30 + 1024)

// Sensor Update Interval
#define SENSOR_UPDATE_MS    5000            // Time between smoke sensor readings in milliseconds

// DHT11 Temperature and Humidity Sensor Configuration
#define DHT11_GPIO          47              // Data pin for the DHT11 sensor
#define DHT11_UPDATE_MS     2000            // The DHT11 cannot be read faster than once every 2 seconds

// LVGL Display Buffer Configuration
// Shared between display.c and main.c.
#define LVGL_BUF_LINES      40              // Number of lines allocated for LVGL's double buffering system

// LDR Light Sensor (Analog) Configuration
#define LDR_AOUT_GPIO       6               // Analog pin for reading light intensity
#define LDR_ADC_CHANNEL     ADC_CHANNEL_5   // GPIO6 corresponds to ADC1_CH5

// PIR Motion Sensor Configuration
#define PIR_GPIO            5               // Digital output pin from the PIR sensor
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

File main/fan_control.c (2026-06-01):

// L298N DC Fan PWM Driver
// LEDC TIMER_1 / CHANNEL_1
// 25 kHz, 8-bit resolution
// FAN_IN4_GPIO controls direction (HIGH means fan moves forward)
// FAN_ENA_GPIO controls the PWM speed

#include "fan_control.h"
#include "config.h"

#include "driver/ledc.h"
#include "driver/gpio.h"
#include "esp_log.h"

// Tag used for ESP logging to identify messages from the fan controller.
static const char *TAG = "fan";

// Configures the GPIO and LEDC timer/channel required to control the fan.
// We use the ESP32's LEDC peripheral to generate a hardware PWM signal
// so the CPU doesn't have to manually toggle the pin.
esp_err_t fan_control_init(void)
{
    // Set up the direction pin for the motor driver.
    // We configure it as an output without pull-up or pull-down resistors.
    gpio_config_t gc = {
        .pin_bit_mask = 1ULL << FAN_IN4_GPIO,
        .mode         = GPIO_MODE_OUTPUT,
        .pull_up_en   = GPIO_PULLUP_DISABLE,
        .pull_down_en = GPIO_PULLDOWN_DISABLE,
        .intr_type    = GPIO_INTR_DISABLE,
    };
    ESP_ERROR_CHECK(gpio_config(&gc));
    
    // Start with the fan turned off by default.
    gpio_set_level(FAN_IN4_GPIO, 0);

    // Configure the LEDC timer.
    // We set the frequency and resolution for the PWM signal.
    ledc_timer_config_t timer_cfg = {
        .speed_mode      = LEDC_LOW_SPEED_MODE,
        .timer_num       = FAN_LEDC_TIMER,
        .duty_resolution = FAN_DUTY_RES,
        .freq_hz         = FAN_PWM_FREQ_HZ,
        .clk_cfg         = LEDC_AUTO_CLK,
    };
    ESP_ERROR_CHECK(ledc_timer_config(&timer_cfg));

    // Configure the LEDC channel and link it to the timer we just created.
    // This attaches the PWM signal to the specific GPIO pin connected to the motor driver.
    ledc_channel_config_t ch_cfg = {
        .gpio_num   = FAN_ENA_GPIO,
        .speed_mode = LEDC_LOW_SPEED_MODE,
        .channel    = FAN_LEDC_CHANNEL,
        .timer_sel  = FAN_LEDC_TIMER,
        .duty       = 0,
        .hpoint     = 0,
        .intr_type  = LEDC_INTR_DISABLE,
    };
    ESP_ERROR_CHECK(ledc_channel_config(&ch_cfg));

    ESP_LOGI(TAG, "Fan ready: IN4=GPIO%d ENA=GPIO%d @ %luHz",
             FAN_IN4_GPIO, FAN_ENA_GPIO, (unsigned long)FAN_PWM_FREQ_HZ);
    return ESP_OK;
}

// Adjusts the fan speed by updating the PWM duty cycle.
// Also ensures the direction pin is HIGH if the fan should be spinning.
void fan_set_duty(uint8_t duty)
{
    // If duty is greater than 0, enable the direction pin so the motor can turn.
    // Otherwise, disable it to ensure the motor stops completely.
    gpio_set_level(FAN_IN4_GPIO, duty > 0 ? 1 : 0);
    
    // Apply the new duty cycle to the LEDC hardware.
    ledc_set_duty(LEDC_LOW_SPEED_MODE, FAN_LEDC_CHANNEL, duty);
    ledc_update_duty(LEDC_LOW_SPEED_MODE, FAN_LEDC_CHANNEL);
}

// Helper functions for common fan speeds.

// Stops the fan completely.
void fan_off(void)  { fan_set_duty(0);   }

// Runs the fan at partial capacity (roughly 30% power for high voltage setups).
void fan_half(void) { fan_set_duty(80);  }

// Runs the fan at a higher capacity (roughly 60% power for high voltage setups).
void fan_full(void) { fan_set_duty(160); }

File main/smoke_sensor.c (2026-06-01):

// MQ135 Smoke/Gas Sensor and LDR Sensor Driver
// Utilizes analog readings, enforces warmup times, and applies averaging for noise filtration.

#include "smoke_sensor.h"
#include "config.h"

#include "esp_adc/adc_oneshot.h"
#include "esp_log.h"
#include "esp_timer.h"
#include "freertos/FreeRTOS.h"
#include "freertos/task.h"

// Tag used for ESP logging to identify messages related to the smoke sensor.
static const char *TAG = "smoke";

// Handle for the ADC one-shot unit used to read analog values.
static adc_oneshot_unit_handle_t s_adc    = NULL;

// Timestamp of when the sensor was initialized, used to calculate the warmup period.
static int64_t                   s_t_init = 0;

// Initializes the ADC unit and configures the specific channel for the smoke sensor.
// This sets up the hardware so we can read the analog voltage produced by the MQ135.
esp_err_t smoke_sensor_init(void)
{
    // Create and configure a new ADC one-shot unit.
    // We disable the ULP (Ultra Low Power) mode because we don't need it here.
    adc_oneshot_unit_init_cfg_t unit_cfg = {
        .unit_id  = ADC_UNIT_1,
        .ulp_mode = ADC_ULP_MODE_DISABLE,
    };
    ESP_ERROR_CHECK(adc_oneshot_new_unit(&unit_cfg, &s_adc));

    // Configure the specific channel for the smoke sensor.
    // We use 11dB attenuation to allow measuring voltages up to roughly 3.3V,
    // and set the resolution to the default 12 bits (0-4095 range).
    adc_oneshot_chan_cfg_t ch_cfg = {
        .atten    = ADC_ATTEN_DB_12,
        .bitwidth = ADC_BITWIDTH_DEFAULT,
    };
    ESP_ERROR_CHECK(adc_oneshot_config_channel(s_adc, SMOKE_ADC_CHANNEL, &ch_cfg));

    // Record the current time so we know when the warmup period started.
    s_t_init = esp_timer_get_time();
    
    ESP_LOGI(TAG, "MQ135 initialized (GPIO%d). Waiting %d ms for warmup.",
             SMOKE_AOUT_GPIO, SMOKE_WARMUP_MS);
    return ESP_OK;
}
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

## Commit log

2026-05-16 Complete SmartLab Asistan: all phases done, web UI, RAG, smoke/fan control
2026-05-25 Fix RFID, TFT crash, audio pipeline and integrate all phases
    [config.h, display.c, main.c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]
2026-05-29 feat: add LDR, PIR, flame, and vibration sensors
    [config.h, dht11.c, fan_control.c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]
2026-05-31 feat: RAG pipeline with PDF docs, image resize, LLM timeout fix
    - Add rag_pdf/ with multimeter, ESP32-S3, ILI9341 datasheets (1607 chunks)
    - Update rag.py KB_DIR to point to rag_pdf/
    - Resize uploaded photos to 800px JPEG before storing (50x smaller for LLM)
    - Increase LLM timeout: 60s text-only, 120s vision
    - Update CLAUDE.md: new pins, new sensors, rag_pdf path
2026-05-31 Fix: Login bug issue is solved
    [ui_smartlab.c]
2026-05-31 feat: tabbed dashboard UI (Chat/Sensors/Photo), sensor broadcast from ESP32, session data API
2026-05-31 restore: tabbed dashboard UI (Chat/Sensors/Photo) - server RFID guard already in main.py
2026-05-31 perf: sensor broadcast 5s->1s, web UI poll 3s->1s for realtime updates
2026-05-31 feat: sensor WS push, last-seen timestamps, cap PDF chunks at 200
2026-05-31 fix: sensor broadcast 50ms fast-path for vib/pir/flame state changes, cap PDF chunks 200
    [main.c]
2026-05-31 fix: image takes priority over RAG, tighten RAG threshold 0.8->0.45, Piper in-memory TTS, LLM tokens 200->80
2026-05-31 fix: use synthesize_wav API, fallback chain for different piper versions
2026-05-31 fix: second photo upload - poll no longer disables button when new file selected
2026-05-31 fix: shared DHT11 vars to prevent vTaskSuspendAll RFID interference, MFRC522 recovery after 5 fails
    [main.c]
2026-05-31 feat: fan control from web UI (on/off/speed/mode), temp auto-fan at 27C
2026-05-31 Fix: DHT11 bug issue fixed
    [dht11.c, main.c]
2026-05-31 feat: sync logout - web UI logout sends command to ESP32, TFT returns to RFID screen
2026-05-31 ui: professional TFT redesign - header bar, icon circles, dark cards, color accents per state
    [ui_smartlab.c]
2026-06-01 feat(ui): remove QR code from READY screen, show server URL as text; fix rfiddouble-init guard; fix logout to preserve WebSocket connection
    [rfid.c, ui_smartlab.c]
2026-06-01 fix: auto-retry server connection every 10s, show active session on web UI load
    [main.c]
2026-06-01 fix: prevent smoke_task from overriding temperature-based fan control
    [config.h, main.c]
2026-06-01 feat: add proportional LDR-LED control, sync web UI, and fix RFID 00000000 noise bug
    [config.h, led_strip_ctrl.c, main.c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]
2026-06-01 docs: add hardware circuit diagram to assets
    [iot-final.fzz]
